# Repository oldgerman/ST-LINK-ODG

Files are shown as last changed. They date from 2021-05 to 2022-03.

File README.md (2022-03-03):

# ST-LINK-ODG

> USB-C口的ST-LINK模块（0603元件100%，易于焊接 ）

ST官方的Nucleo-64板子用ST-LINK有点不方便，前段时间看到稚晖君开源了USB-C口的[ST-Link-Nano](https://github.com/peng-zhihui/ST-Link-Nano)，心血来潮也想做一个，无奈本人手残焊不来0402元件，遂准备做一个0603版本的。以前一直用Eagle，听朋友[稀饭放姜](https://space.bilibili.com/393224264?spm_id_from=333.788.b_765f7570696e666f.1)说Kicad更香，跟着他的[视频教程](https://www.bilibili.com/video/BV12J411z7j7?from=search&seid=1305491858116785113)快速学习了一个，于是整出来了：

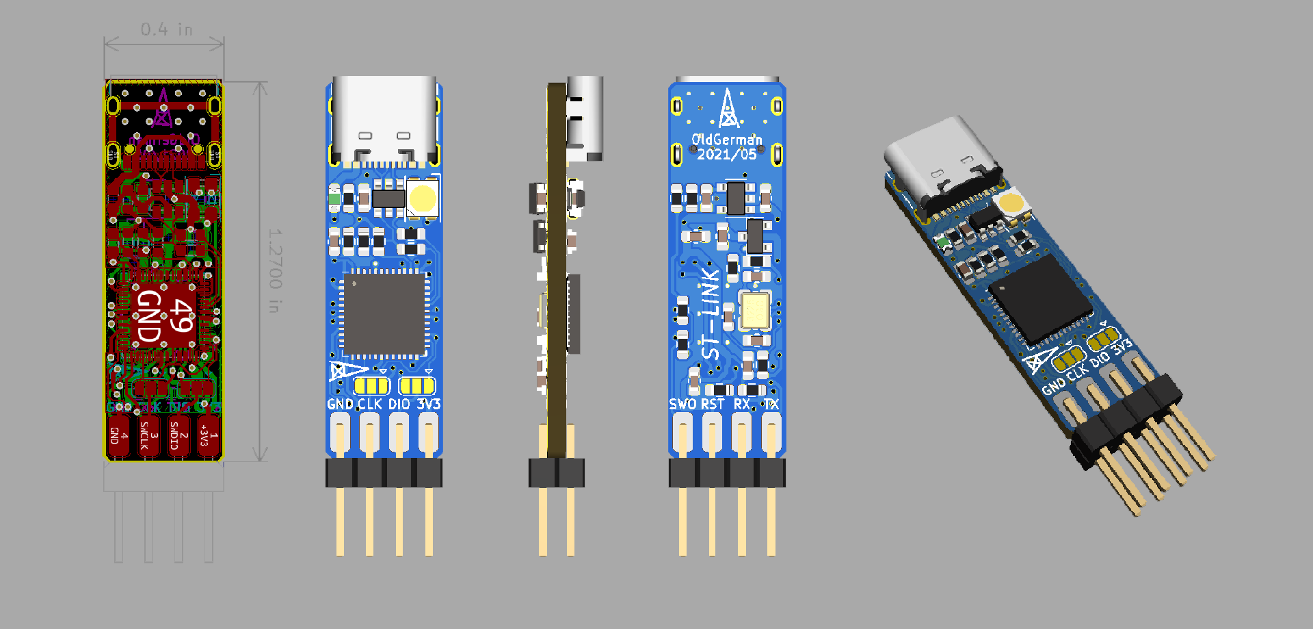
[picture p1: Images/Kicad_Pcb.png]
Kicad_Pcb


## Notice

### PCB工艺参数

- PCB厚度1.6mm，双面板
- 线宽/线距6mil，最小过孔0.3mm，最小阻焊桥>5mil

### 物料

- PCB上有一个3528封装的LED，是红-普绿双色反极的（与ST官方开发板一样），”普绿“就是黄绿色的意思，不要与常见的红-翠绿双色LED混淆（翠绿真心丑还倍儿亮），[推荐购买链接](https://item.taobao.com/item.htm?id=569456631431)，也可以用普通0603 LED代替

- USBLC6-2SC6是USB2.0总线ESD保护器件

- USB D+ 的1.5K上拉电阻经S8050到3.3V，B极由MCU的GPIO控制，与ST的原理图一致没有省

### 跳线

  红色跳线被下载固件，蓝色跳线当ST-LINK

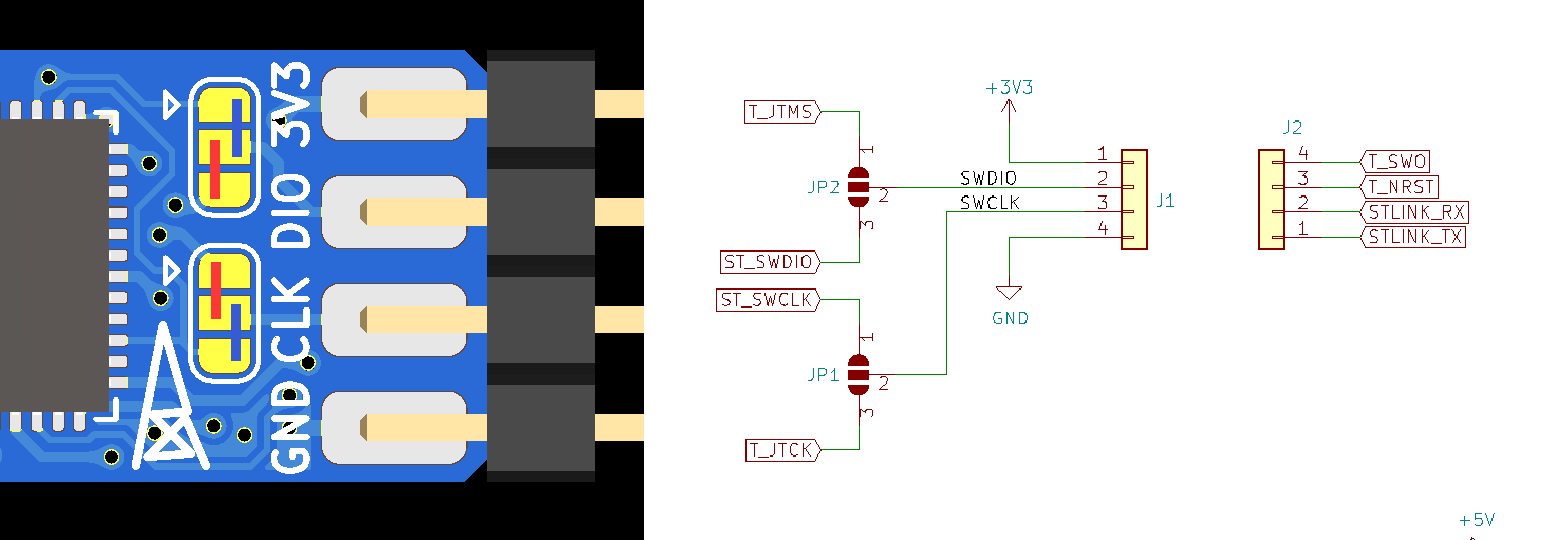
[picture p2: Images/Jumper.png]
Jumper
  

## 焊接测试

> S8050左右脚位反了，待修改，目前反过来焊接S8050能正常使用烧录

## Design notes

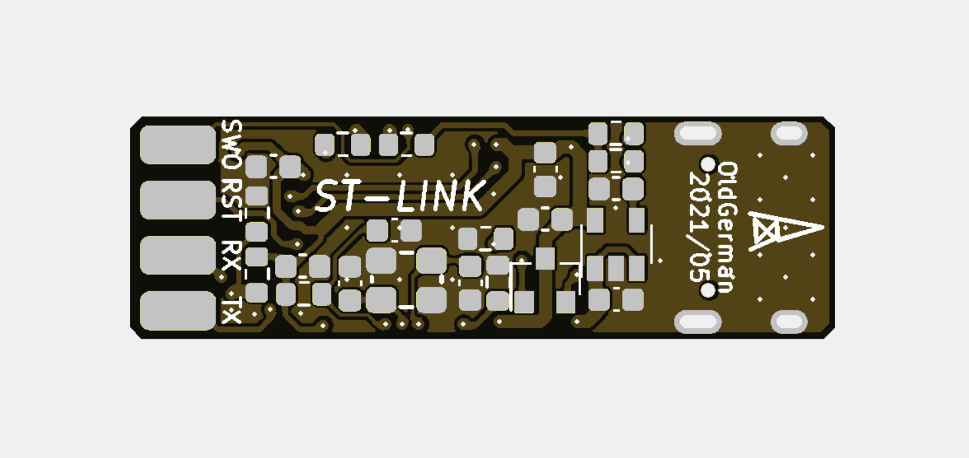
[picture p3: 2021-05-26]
Images/JLC_views(2).png

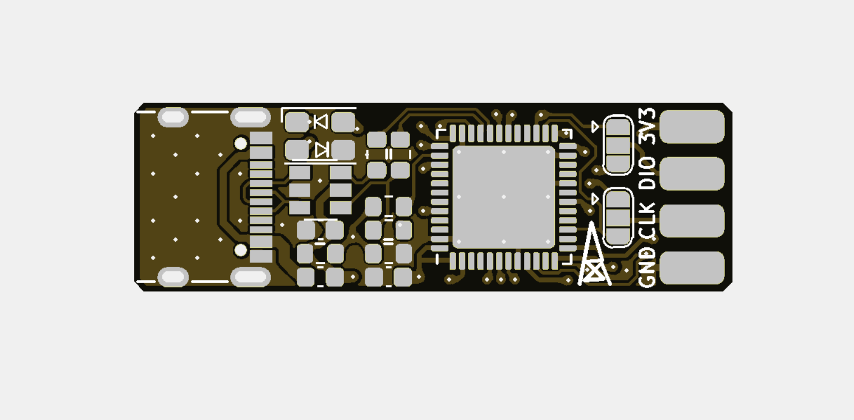
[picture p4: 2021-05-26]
Images/JLC_views(1).png

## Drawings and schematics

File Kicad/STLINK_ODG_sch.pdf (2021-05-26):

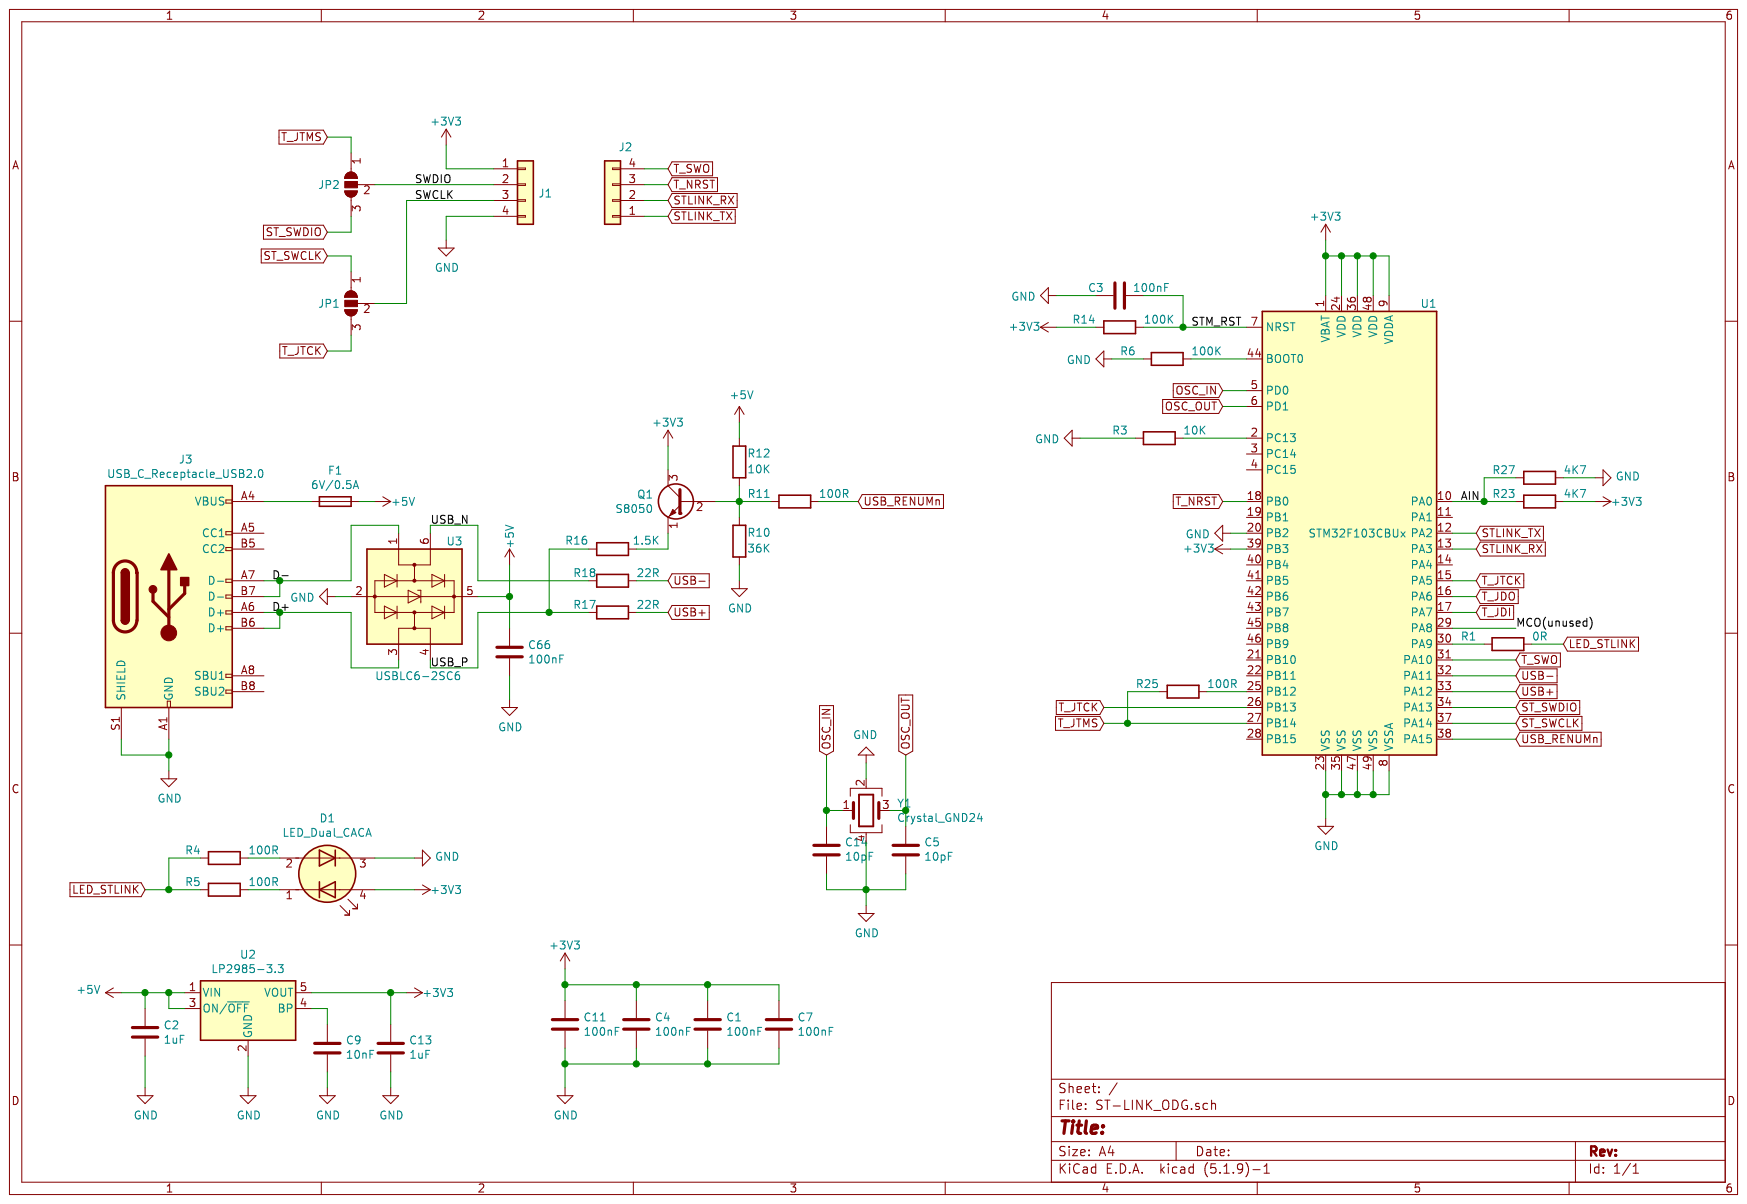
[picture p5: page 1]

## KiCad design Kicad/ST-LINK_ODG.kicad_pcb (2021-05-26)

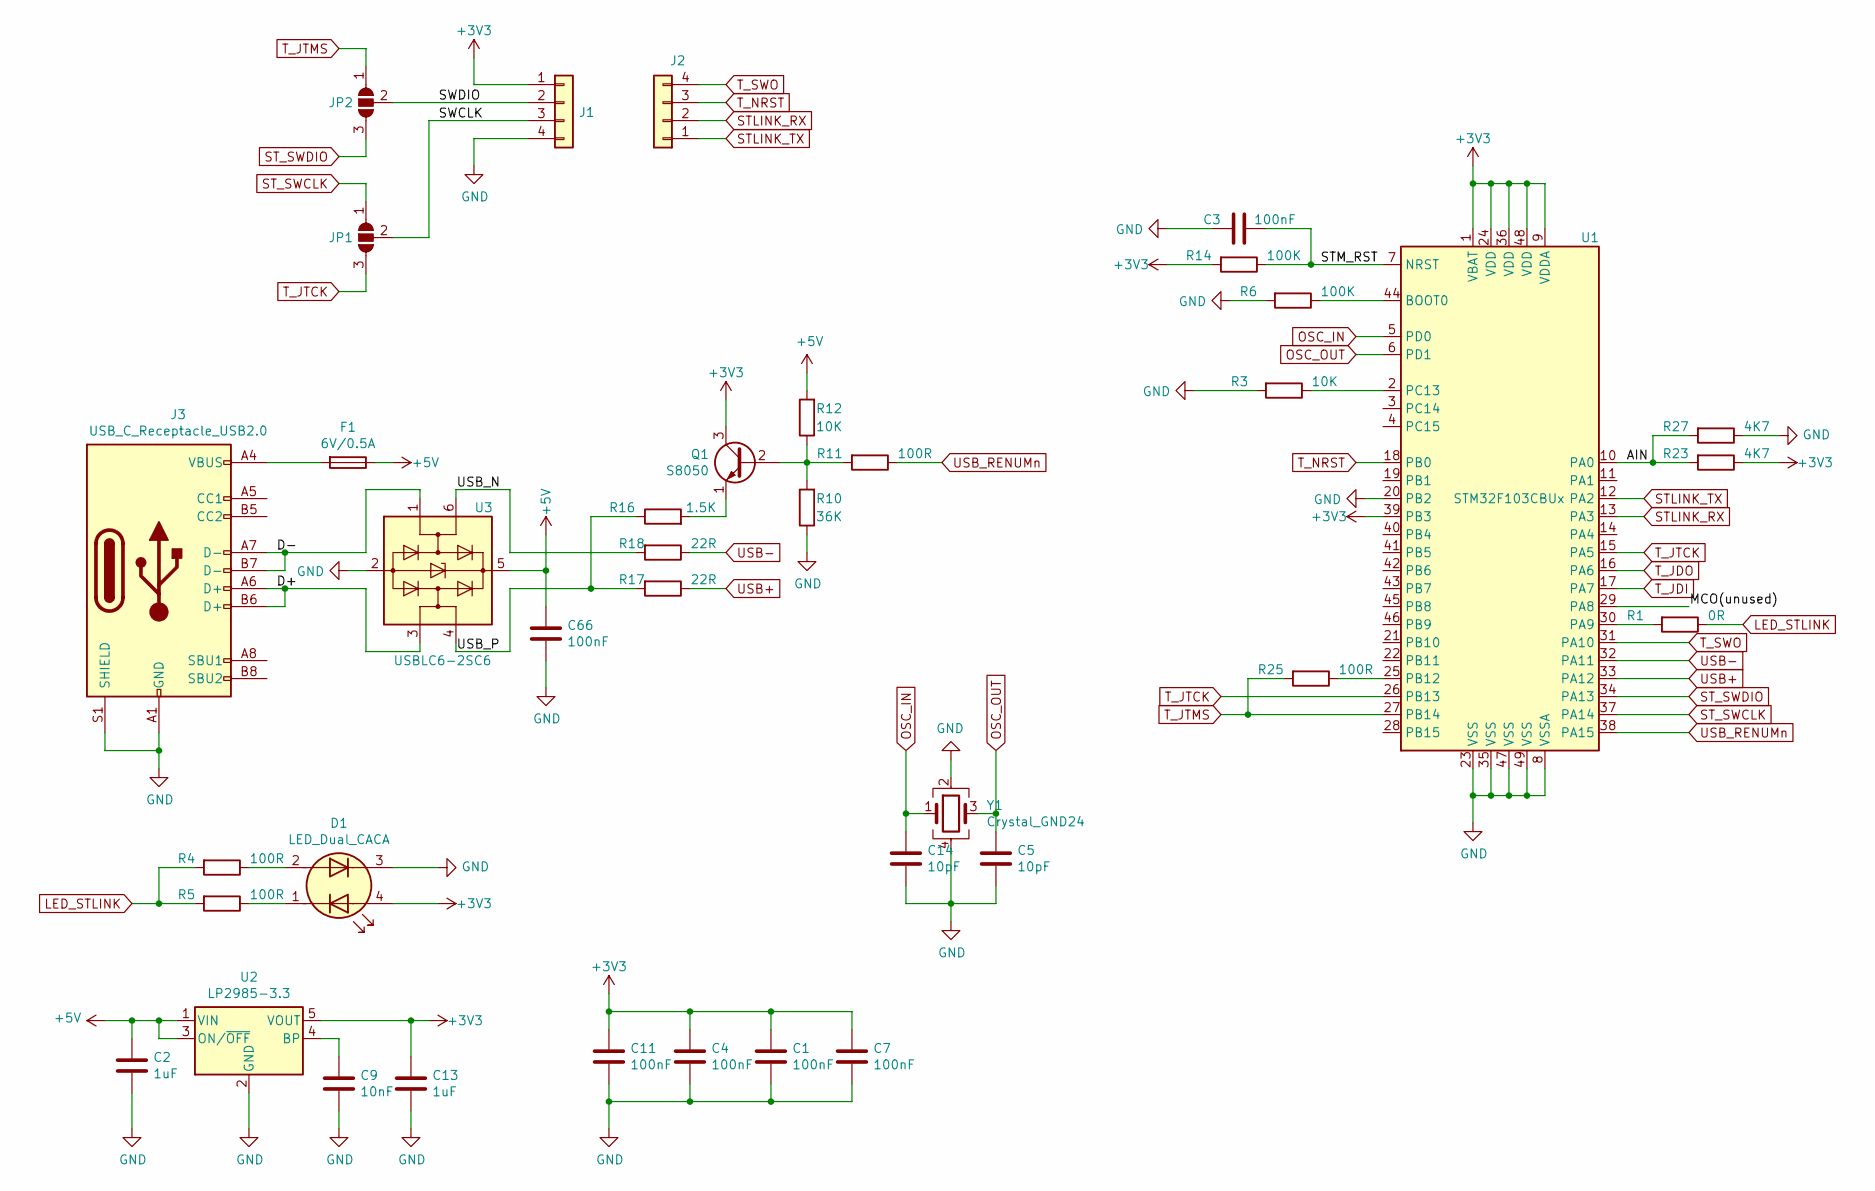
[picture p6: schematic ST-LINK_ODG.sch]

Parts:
C1, C3, C4, C7, C11, C66: 100nF; C_0603_1608Metric
C2, C13: 1uF; C_0603_1608Metric
C5, C14: 10pF; C_0603_1608Metric
C9: 10nF; C_0603_1608Metric
D1: LED_Dual_CACA; LED_Cree-PLCC4_3.2x2.8mm_CCW
F1: 6V/0.5A; Fuse_0603_1608Metric
J1, J2: Conn_01x04; PinHeader_1x04_P2.54mm_Horizontal_SMD_PAD_No_Slik
J3: USB_C_Receptacle_USB2.0; USB_C_Receptacle_XKB_U262-16XN-4BVC11_less_Slik
JP1, JP2: SolderJumper_3_Open; SolderJumper-3_Mini_Open_RoundedPad
Q1: S8050; SOT-23
R1: 0R; R_0603_1608Metric
R3, R12: 10K; R_0603_1608Metric
R4, R5, R11, R25: 100R; R_0603_1608Metric
R6, R14: 100K; R_0603_1608Metric
R10: 36K; R_0603_1608Metric
R16: 1.5K; R_0603_1608Metric
R17, R18: 22R; R_0603_1608Metric
R23, R27: 4K7; R_0603_1608Metric
U1: STM32F103CBUx; QFN-48-1EP_7x7mm_P0.5mm_EP5.45x5.45mm
U2: LP2985-3.3; SOT-23-5
U3: USBLC6-2SC6; SOT-23-6
Y1: Crystal_GND24; 3.2X2.5_KX-7

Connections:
+3V3: C1.1, C4.1, C7.1, C11.1, C13.2, D1.4 (K1), J1.1, Q1.3 (C), R14.2, R23.1, U1.1 (VBAT), U1.9 (VDDA), U1.24 (VDD), U1.36 (VDD), U1.39 (PB3), U1.48 (VDD), U2.5 (VOUT)
+5V: C2.1, C66.1, F1.1, R12.2, U2.1 (VIN), U2.3 (ON/~OFF~), U3.5 (VBUS)
/AIN: R23.2, R27.2, U1.10 (PA0)
/D+: J3.A6 (D+), J3.B6 (D+), U3.3 (I/O2)
/D-: J3.A7 (D-), J3.B7 (D-), U3.1 (I/O1)
/MCO(unused): U1.29 (PA8)
/STM_RST: C3.1, R14.1, U1.7 (NRST)
/SWCLK: J1.3, JP1.2 (C)
/SWDIO: J1.2, JP2.2 (C)
/USB_N: R18.2, U3.6 (I/O1)
/USB_P: R16.1, R17.2, U3.4 (I/O2)
GND: C1.2, C2.2, C3.2, C4.2, C5.1, C7.2, C9.1, C11.2, C13.1, C14.1, C66.2, D1.3 (K2), J1.4, J3.A1 (GND), J3.A12 (GND), J3.B1 (GND), J3.B12 (GND), J3.S1 (SHIELD), R3.2, R6.2, R10.1, R27.1, U1.8 (VSSA), U1.20 (PB2), U1.23 (VSS), U1.35 (VSS), U1.47 (VSS), U1.49 (VSS), U2.2 (GND), U3.2 (GND), Y1.2, Y1.4
LED_STLINK: R1.1, R4.2, R5.2
unnamed: C9.2, U2.4 (BP)
unnamed: D1.1 (A1), R5.1
unnamed: D1.2 (A2), R4.1
unnamed: F1.2, J3.A4 (VBUS), J3.A9 (VBUS), J3.B4 (VBUS), J3.B9 (VBUS)
unnamed: Q1.1 (E), R16.2
unnamed: Q1.2 (B), R10.2, R11.2, R12.1
unnamed: R1.2, U1.30 (PA9)
unnamed: R3.1, U1.2 (PC13)
unnamed: R6.1, U1.44 (BOOT0)
unnamed: R25.1, U1.25 (PB12)
OSC_IN: C14.2, U1.5 (PD0), Y1.1
OSC_OUT: C5.2, U1.6 (PD1), Y1.3
STLINK_RX: J2.2, U1.13 (PA3)
STLINK_TX: J2.1, U1.12 (PA2)
ST_SWCLK: JP1.1 (A), U1.37 (PA14)
ST_SWDIO: JP2.3 (B), U1.34 (PA13)
T_JDI: U1.17 (PA7)
T_JDO: U1.16 (PA6)
T_JTCK: JP1.3 (B), U1.15 (PA5), U1.26 (PB13)
T_JTMS: JP2.1 (A), R25.2, U1.27 (PB14)
T_NRST: J2.3, U1.18 (PB0)
T_SWO: J2.4, U1.31 (PA10)
USB+: R17.1, U1.33 (PA12)
USB-: R18.1, U1.32 (PA11)
USB_RENUMn: R11.1, U1.38 (PA15)

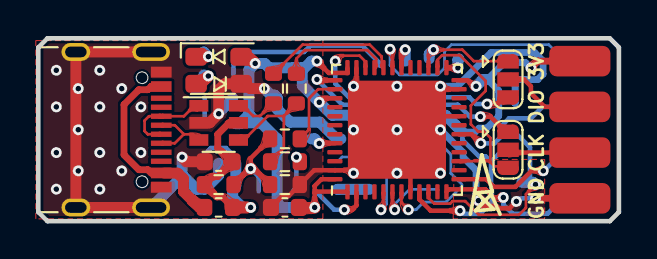
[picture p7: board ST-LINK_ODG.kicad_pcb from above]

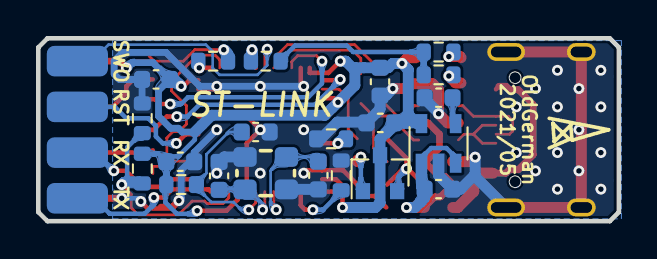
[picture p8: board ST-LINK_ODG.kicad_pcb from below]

Board: 2 copper layers, 32.3 x 10.2 mm, 38 parts (22 on the bottom side), 35 nets.
